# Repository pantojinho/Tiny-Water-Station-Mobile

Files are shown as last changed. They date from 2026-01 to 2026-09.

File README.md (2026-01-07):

# Tiny Water Station Mobile - ESP32

**Project:** Atmospheric Telemetry and Aviation Mobile Unit

**Version:** 1.1 (Updated with BMM350)

**Processor:** ESP32-S3 (AI Enabled)

---

## 1. Overview

The **Tiny Water Station Mobile** is a high-performance development board (DEV Board) designed for weather balloon missions, critical environmental monitoring, and aviation assistance. The system combines industrial-grade precision sensors with long-range telemetry and edge artificial intelligence processing.

---

## 2. Core Specifications

The system is centered on the **ESP32-S3-WROOM-1-N16R8** module, chosen for:

* **Processing:** Dual-core with AI acceleration instructions (TensorFlow Lite Micro).
* **Memory:** 16MB Flash and 8MB PSRAM (essential for sensor buffers and LCD graphics).
* **Datalogger:** Integrated MicroSD slot for "Black Box" recording (flight logs in .csv).

---

## 3. Sensor Architecture (I2C Bus)

The board uses a shared I2C bus (GPIO 47 SDA / GPIO 48 SCL) with the following components:

| Sensor | Model | Function | Critical Advantage |
| --- | --- | --- | --- |
| **Environment** | Bosch BME688 | Gas (VOC/VSC), Temp and Humidity | AI for gas and odor detection |
| **Altimetry** | Bosch BMP581 | Pressure and Altitude Pro | 5cm precision (high-sensitivity vario) |
| **Inertial** | Bosch BMA400 | Low-Power Accelerometer | Impact detection and power saving |
| **Compass** | **Bosch BMM350** | **High-Precision Magnetometer** | **Heading correction and stable orientation** |
| **Light/UV** | Lite-On LTR-390 | UV Index and Luxmetry | Solar radiation monitoring |
| **Battery** | MAX17048 | Fuel Gauge (Monitoring) | Real battery percentage without charge loss |

---

## 4. External Module Integration (Off-Board)

To ensure flexibility and facilitate 3D assembly, the items below are connected via headers, not soldered directly to the main SMD board.

### 4.1. GPS Module (AliExpress)

The PCB will have a dedicated **6-pin female header** (2.54mm pitch) for the external GPS module. The GPS module from AliExpress comes with a 6-pin female connector.

* **PCB Pinout (6-pin female header):**
* **Pin 1:** VCC - 3.3V (AP2112K regulator output)
* **Pin 2:** GND - Common ground
* **Pin 3:** RXD (GPIO 17) - Connects to GPS module TX
* **Pin 4:** TXD (GPIO 18) - Connects to GPS module RX
* **Pin 5:** Reserved / NC
* **Pin 6:** Reserved / NC

*Note: Standard GPS modules typically use 4 pins (VCC, GND, TX, RX), but the AliExpress module uses a 6-pin connector. Pins 5 and 6 are reserved for future use or can be left unconnected.*

### 4.2. Power System and Battery

* **Type:** Li-Po 3.7V Battery (Recommended above 1000mAh for long missions).
* **Connector:** JST-PH 2.0mm 2-pin (Soldered on PCB).
* **Charging:** Integrated MCP73831 circuit for USB-C charging.
* **Safety:** DW01A protection circuit to prevent overcharge and deep discharge.

---

## 5. Interface and Expansion

### 5.1. Communication and Display

* **LoRa CC68 915MHz:** Long-distance data transmission (dedicated SPI).
* **IPS LCD Display 1.14":** Real-time visual feedback (shared SPI).
* **Antennas:** U.FL (IPEX) connectors for radio and GPS.

### 5.2. Expansion Header (Future-Proof)

A side connector (1x08) for future additions:

* `3.3V`, `GND`, `SDA`, `SCL`, `GPIO 1 (Analog)`, `GPIO 2`, `5V (VBUS)`.

---

## 6. Firmware Reference Pinout

| Feature | ESP32-S3 Pin | Note |
| --- | --- | --- |
| **I2C SDA / SCL** | GPIO 47 / 48 | Bus for all sensors |
| **UART TX / RX** | GPIO 18 / 17 | Communication with external GPS |
| **SPI MOSI/MISO/SCK** | GPIO 11 / 13 / 12 | Common bus (LoRa, LCD, SD) |
| **LoRa CS / DIO1** | GPIO 10 / 14 | Semtech radio control |
| **SD Card CS** | GPIO 21 | Datalogger selection |
| **LCD CS / DC** | GPIO 9 / 15 | IPS Display control |

---

## 7. Notes for 3D Design and PCB (China)

1. **Magnetometer (BMM350):** Position the BMM350 as far as possible from magnetic sources (such as speakers or DC-DC converter inductors) to avoid compass interference.
2. **Air Flow:** The BME688 sensor needs an opening in the 3D case to "breathe" external air, otherwise it will only measure the internal case temperature.
3. **GPS Module:** The 6-pin female connector should be positioned so that the external module cable does not pass over the ESP32-S3 antenna (WiFi/BT).
4. **Battery:** In the 3D design, provide a mechanical support for the Li-Po battery. Avoid leaving it loose, as in weather balloons vibration and wind can disconnect the JST.

---

## 8. Additional Documentation

For more technical details and contribution guidelines, see:

* **📦 [PCB/Hardware](PCB/README.md)** - Schematics, layouts, BOM and 3D design
* **💻 [Software](software/README.md)** - Firmware, drivers, tools and tests
* **🤝 [Contributing](CONTRIBUTING.md)** - Complete guide for contributors (PCB and Software)

---

## 9. License

This project is licensed under the **MIT License**. See the [LICENSE](LICENSE) file for more details.

---

*Documentation generated to support hardware development and software integration.*

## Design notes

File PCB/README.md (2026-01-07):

# PCB / Hardware - Tiny Water Station Mobile

This folder contains all files related to hardware design, schematics, PCB layouts, and technical documentation for manufacturing.

---

## 📁 Directory Structure

```
PCB/
├── schematics/           # Electronic schematics
├── layouts/              # PCB Layouts (EDA files)
├── bom/                  # Bill of Materials (Component list)
├── 3d-models/            # 3D Models (case, brackets, etc.)
├── documentation/        # Technical documentation
└── revisions/            # Version control per hardware
```

---

## 📋 Current Content

### Version 1.1 (Current)

This version uses the following main components:

- **MCU:** ESP32-S3-WROOM-1-N16R8 (16MB Flash, 8MB PSRAM)
- **I2C Sensors:**
  - BME688 - Temperature, Humidity, Gas (VOC/VSC)
  - BMP581 - Pressure and Altitude Pro
  - BMA400 - Low-Power Accelerometer
  - BMM350 - High-Precision Magnetometer
  - LTR-390 - UV Index and Luxmetry
  - MAX17048 - Battery Fuel Gauge

- **Communication:**
  - LoRa CC68 915MHz
  - GPS (external 6-pin female connector, 2.54mm pitch)

- **Interfaces:**
  - IPS LCD Display 1.14" (SPI)
  - MicroSD Card (SPI)
  - Expansion Header 1x08

---

## 🛠️ Recommended Tools

### PCB Design

- **KiCad (7.x or higher):** Free and open-source software
- **Altium Designer:** Professional tool (requires license)
- **EasyEDA:** Web-based alternative

### 3D Modeling

- **Fusion 360:** Professional CAD (free for educational use)
- **FreeCAD:** Open-source alternative
- **OpenSCAD:** Script-based for parametric models

### BOM and Documentation

- **Excel/Google Sheets:** For component lists
- **Markdown:** For technical documentation

---

## 📌 Important Design Notes

### Sensor Placement

1. **BMM350 (Magnetometer):**
   - Position as far as possible from magnetic sources
   - Avoid DC-DC converter inductors
   - Keep distance from speakers (if any)

2. **BME688 (Gas Sensor):**
   - The 3D case needs an opening for ventilation
   - Air flow required for accurate measurements
   - Avoid hermetic encapsulation

3. **Antennas:**
   - U.FL connectors for GPS and LoRa
   - Keep free area for radiation
   - Avoid metal traces under antennas

### Manufacturing Requirements

- **Minimum trace width:** 6 mil (0.15mm) for signals
- **Minimum clearance:** 6 mil (0.15mm)
- **Mounting vias:** Use tented vias
- **Solder mask:** Cover critical areas
- **Silkscreen:** Clear markers for SMD components

### Required Gerber Files

When sending for manufacturing, include:
- `.GTL` - Top copper layer
- `.GBL` - Bottom copper layer
- `.GTO` - Top silkscreen
- `.GBO` - Bottom silkscreen
- `.GBS` - Bottom solder mask
- `.GTS` - Top solder mask
- `.GBO` - Board outline
- `.GTP` - Top paste
- `.GBP` - Bottom paste

---

## 🔄 Version Control

Each hardware version should have its own folder in `revisions/` section:

```
revisions/
├── v1.0/
│   ├── schematics/
│   ├── layouts/
│   └── bom_v1.0.csv
└── v1.1/
    ├── schematics/
    ├── layouts/
    └── bom_v1.1.csv
```

### Versioning Convention

- **Major:** Changes that make versions incompatible
- **Minor:** Backward-compatible additions
- **Patch:** Bug fixes

---

## 📦 Bill of Materials (BOM)

### Recommended Format

```csv
Ref,Value,Footprint,Quantity,Manufacturer,Part Number,Supplier,Supplier Part Number,Notes
U1,ESP32-S3-WROOM-1,N16R8,1,Espressif,ESP32-S3-WROOM-1-N16R8,Digikey,2877-ESP32-S3-WROOM-1-N16R8-CT,
U2,BME688,LGA-8,1,Bosch,BME688,Digikey,828-1083-1-ND,
...
```

### Required Fields

- **Ref:** Reference on PCB (U1, R1, C1, etc.)
- **Value:** Component value (10k, 0.1uF, etc.)
- **Footprint:** Footprint used in layout
- **Quantity:** Required quantity
- **Part Number:** Manufacturer part number
- **Supplier Part Number:** Supplier part number

---

## 🎯 3D Case Design

### Minimum Requirements

1. **Required Openings:**
   - BME688 sensor (ventilation)
   - LCD Display (visible)
   - USB-C connector (charging)
   - LED indicators
   - Antennas (GPS/LoRa) - transparent or external area

2. **Battery Support:**
   - Fixed compartment for Li-Po battery
   - Avoid vibration that can disconnect JST
   - Easy access for replacement

3. **Assembly:**
   - Mounting holes for PCB
   - Appropriate spacers/standoffs
   - Consider ESP32 thermal dissipation

### 3D Printing Files

Recommended to provide:
- **STL/OBJ:** For direct printing
- **STEP:** For CAD modification
- **Printing Instructions:**
  - Recommended material (PLA/PETG/ABS)
  - Infill %
  - Temperature
  - Layers

---

## 🔧 Assembly and Soldering

### Suggested Assembly Order

1. Passive components (resistors, capacitors)
2. Connectors and headers
3. Integrated circuits
4. Mechanical components (buttons, LEDs)
5. Modules via headers (GPS, LoRa)

### Soldering Notes

- Use flux solder for SMD components
- Recommended temperature: 350-370°C
- Maximum contact time: 3 seconds per pin
- Check continuity after assembly

---

## 📞 Contributing with Hardware

To contribute with new designs or improvements:

1. Create a branch following the pattern: `hardware/name-of-change`
2. Make your modifications
3. Test the schematic (DRC/ERC)
4. Update BOM if necessary
5. Document the changes
6. Open a Pull Request with detailed description

Consult the file `../CONTRIBUTING.md` for more details about the contribution process.

---

## 📚 Additional Resources

- [Component Datasheets](../README.md#3-sensor-architecture-i2c-bus)
- [Complete Pinout](../README.md#6-firmware-reference-pinout)
- [Contribution Documentation](../CONTRIBUTING.md)
- [China Manufacturing Guidelines](../README.md#7-notes-for-3d-design-and-pcb-china)

---

**Last Update:** 2026
**Version:** 1.1

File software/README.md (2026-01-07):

# Software - Tiny Water Station Mobile

This folder contains all source code, libraries, tools, and documentation related to software development for the ESP32-S3 of Tiny Water Station Mobile.

---

## 📁 Directory Structure

```
software/
├── firmware/             # Main firmware (ESP32-S3)
│   ├── src/              # Source files (.cpp, .c, .ino)
│   │   ├── main.cpp      # Main file
│   │   ├── sensors/      # Sensor drivers
│   │   ├── comms/        # Communication (LoRa, GPS, SD)
│   │   ├── display/      # LCD control
│   │   └── utils/        # Utility functions
│   ├── include/          # Headers (.h)
│   ├── platformio.ini    # PlatformIO configuration
│   └── CMakeLists.txt    # Build system (ESP-IDF)
├── libraries/            # Custom libraries
├── tools/                # Scripts and utilities
├── tests/                # Unit and integration tests
└── documentation/        # Technical documentation and APIs
```

---

## 🚀 Getting Started

### Requirements

- **PlatformIO** (CLI or VS Code extension) - Recommended
- **ESP-IDF** (optional, for native builds)
- **Python 3.8+** (for script tools)
- **Git** (for version control)

### Installation

#### Using PlatformIO (Recommended)

1. Install VS Code: https://code.visualstudio.com/
2. Install PlatformIO extension
3. Clone the repository:
   ```bash
   git clone https://github.com/your-username/Tiny-Water-Station-Mobile.git
   cd Tiny-Water-Station-Mobile/software/firmware
   ```
4. Open in VS Code
5. PlatformIO will automatically detect `platformio.ini`

#### Using ESP-IDF (Alternative)

```bash
# Clone the repository
git clone https://github.com/espressif/esp-idf.git
cd esp-idf
./install.sh esp32s3
. ./export.sh

# Clone and compile the project
git clone https://github.com/your-username/Tiny-Water-Station-Mobile.git
cd Tiny-Water-Station-Mobile/software/firmware
idf.py build
```

### Compilation and Upload

```bash
# Compile
pio run

# Upload to ESP32-S3
pio run --target upload

# Serial monitor
pio device monitor

# All together
pio run --target upload --target monitor
```

---

## 📦 Hardware Components (BOM)

### Required Hardware Components

The following hardware components are required for software development and testing:

| Component | Description | Quantity | Notes |
|---|---|---|---|
| **ESP32-S3-WROOM-1-N16R8** | Main microcontroller module | 1 | 16MB Flash, 8MB PSRAM |
| **BME688** | Environmental sensor (Temp, Humidity, Gas) | 1 | I2C address: 0x77 |
| **BMP581** | High-precision pressure sensor | 1 | I2C address: 0x76 |
| **BMA400** | Low-power accelerometer | 1 | I2C address: 0x40 |
| **BMM350** | High-precision magnetometer | 1 | I2C address: 0x12 |
| **LTR-390** | UV and ambient light sensor | 1 | I2C address: 0x53 |
| **MAX17048** | Battery fuel gauge | 1 | I2C address: 0x36 |
| **SX1262/CC68** | LoRa transceiver module | 1 | 915 MHz, SPI interface |
| **GPS Module** | GPS receiver module | 1 | NMEA protocol, UART interface |
| **IPS LCD Display 1.14"** | Color display | 1 | 135x240 pixels, SPI interface |
| **MicroSD Card** | Data storage | 1 | Minimum 4GB, FAT32 formatted |
| **Li-Po Battery** | Power source | 1 | 3.7V, 1000mAh+ recommended |
| **USB-C Cable** | Programming and charging | 1 | For ESP32 upload and battery charging |
| **JST-PH Connector** | Battery connector | 1 | 2-pin 2.0mm pitch |

### Development Tools

| Tool | Description | Purpose |
|---|---|---|
| **ESP32-S3 DevKit** | Development board | Initial testing before PCB |
| **Logic Analyzer** | Digital signal debugging | I2C, SPI, UART protocol analysis |
| **Multimeter** | Electrical measurements | Voltage, current, continuity testing |
| **Oscilloscope** | Signal visualization | Optional, for advanced debugging |
| **USB-UART Adapter** | Serial communication | GPS module testing (optional) |
| **LoRa Gateway** | LoRa receiver | Testing long-range transmission |

### Optional Accessories

| Component | Description | Purpose |
|---|---|---|
| **Antenna U.FL (LoRa)** | LoRa antenna | 915MHz, dipole or helical |
| **Antenna U.FL (GPS)** | GPS antenna | Active or passive, 1575.42MHz |
| **Push Buttons** | Manual controls | Testing emergency mode, configuration |
| **LEDs** | Status indicators | Visual feedback (optional) |
| **3D Printed Case** | Enclosure | Protects electronics during testing |

### Total Component Count

- **Sensors (I2C):** 6 components
- **Communication Modules:** 2 components (LoRa + GPS)
- **Interfaces:** 2 components (Display + SD Card)
- **Power System:** 2 components (Battery + Charger)
- **Total Unique Components:** ~12 items

### Notes

1. All I2C sensors share the same bus (SDA: GPIO 47, SCL: GPIO 48)
2. SD Card and Display share the same SPI bus (different CS pins)
3. LoRa module uses dedicated SPI interface
4. GPS uses UART (GPIO 17/18)
5. Ensure all sensors are properly powered (3.3V) before testing software

---

## 📡 Sensors and Drivers

### I2C Architecture

All sensors are on the I2C bus:
- **SDA:** GPIO 47
- **SCL:** GPIO 48

### Implemented Drivers

| Sensor | Driver | Base Library | Status |
|---|---|---|---|
| BME688 | `bme688.cpp` | Bosch BSEC 2.x | ✅ Implemented |
| BMP581 | `bmp581.cpp` | Bosch BMP5-Sensor-API | ✅ Implemented |
| BMA400 | `bma400.cpp` | Bosch BMA400-API | ✅ Implemented |
| BMM350 | `bmm350.cpp` | Bosch BMM350-API | ✅ Implemented |
| LTR-390 | `ltr390.cpp` | Adafruit LTR3XX | ✅ Implemented |
| MAX17048 | `max17048.cpp` | Adafruit MAX1704X | ✅ Implemented |

### Initialization Example

```cpp
#include "sensors/bme688.h"

void setup() {
    Serial.begin(115200);
    
    // Initialize BME688
    if (bme688_init()) {
        Serial.println("BME688 initialized successfully!");
    } else {
        Serial.println("Error initializing BME688");
    }
}
```

---

## 📡 Communication

### LoRa (SX126x/CC68)

- **Interface:** SPI
- **Pins:**
  - MOSI: GPIO 11
  - MISO: GPIO 13
  - SCK: GPIO 12
  - CS: GPIO 10
  - DIO1: GPIO 14
- **Frequency:** 915 MHz (South America)
- **Library:** RadioLib

### GPS

- **Interface:** UART
- **Pins:**
  - RX (GPIO 17): Receives from GPS
  - TX (GPIO 18): Sends to GPS
- **Baud rate:** 9600 (configurable)
- **Protocol:** NMEA

### SD Card

- **Interface:** SPI (shared)
- **CS Pin:** GPIO 21
- **Format:** FAT32
- **Function:** Flight datalogger (CSV)

---

## 🖥️ LCD Display

### Specifications

- **Model:** IPS LCD 1.14"
- **Resolution:** 135x240 pixels
- **Interface:** SPI (shared)
- **Pins:**
  - CS: GPIO 9
  - DC: GPIO 15
- **Library:** TFT_eSPI or Adafruit ST7735

### Interface Layout

```
┌─────────────────────────┐
│ Alt: 1245m  Vel: 12.3m/s│  Top bar
├─────────────────────────┤
│ Temp: 25.4°C           │
│ Umid: 68%              │
│ Pres: 1013.2 hPa       │  Sensor data
│ UV: 3.2 Lux: 45000     │
├─────────────────────────┤
│ Bat: 85%  GPS: Fix     │  System status
│ LoRa: TX 2.4k/s        │
└─────────────────────────┘
```

---

## 📊 Datalogger

### Log Format (CSV)

The system records data in CSV format with timestamp:

```csv
timestamp,latitude,longitude,altitude,velocity,temperature,humidity,pressure,gas_resistance,accel_x,accel_y,accel_z,mag_x,mag_y,mag_z,heading,uv_index,lux,battery_percent,lo_rssi
2024-01-06T14:30:00.000Z,-23.5505,-46.6333,1245.2,12.3,25.4,68,1013.2,45000,0.02,0.01,9.81,-23.5,12.3,-45.2,145.3,3.2,45000,85,-65
```

### File Rotation

- **Maximum file size:** 10 MB
- **File name:** `flight_log_YYYYMMDD_HHMMSS.csv`
- **Total logs:** Up to 50 files (after that, the oldest is deleted)

---

## 🔧 Configuration

### platformio.ini

```ini
[env:esp32-s3]
platform = espressif32
board = esp32-s3-devkitc-1
framework = arduino

; Memory settings
board_build.arduino.memory_type = qio_opi
board_build.partitions = huge_app.csv

; Serial settings
monitor_speed = 115200
monitor_filters = esp32_exception_decoder

; Libraries
lib_deps = 
    adafruit/Adafruit Unified Sensor
    adafruit/Adafruit BME680 Library
    RadioLib
    TFT_eSPI
    SPIFFS

; Compilation flags
build_flags = 
    -DARDUINO_USB_MODE=1
    -DARDUINO_USB_CDC_ON_BOOT=1
    -DBOARD_HAS_PSRAM
    -mfix-esp32-psram-cache-issue
```

---

## 🧪 Tests

### Running Tests

```bash
# Test compilation
pio run --target test

# Run all tests
pio test

# Specific test
pio test --target test_bme688
```

### Available Tests

| Test | Description |
|---|---|
| `test_i2c` | Tests communication with all I2C sensors |
| `test_lora` | Tests LoRa transmission and reception |
| `test_gps` | Tests NMEA parsing |
| `test_sd` | Tests SD card writing and reading |
| `test_display` | Tests LCD rendering |

---

## 📚 Documentation

### API Documentation

See the `documentation/` folder for:

- **API Reference:** Complete documentation of public functions
- **Sensor Drivers:** Detailed guide for each sensor
- **Configuration:** Configurable parameters
- **Integration Guide:** Guide for integrating new modules

### Inline Documentation

All public functions have Doxygen documentation:

```cpp
/**
 * @brief Reads current altitude from BMP581 sensor
 * 
 * @return float Altitude in meters above sea level
 * 
 * @note Requires BMP581 to be initialized
 * @see init_bmp581()
 */
float read_altitude();
```

---

## 🎯 Operation Modes

### Normal Mode

Standard operation for monitoring:
- Sensors read at 10 Hz
- LoRa transmitting at 1 Hz
- Display updated at 5 Hz
- Continuous SD logging

### Power Saving Mode

For long missions:
- Sensors read at 1 Hz
- LoRa transmitting at 0.1 Hz (1 msg/10s)
- Display off or updated at 1 Hz
- ESP32 in deep sleep between readings

### Emergency Mode

Triggered by:
- Battery < 10%
- Temperature > 60°C
- Impact detection (BMA400)

Actions:
- Stop LoRa transmissions
- Log only critical data
- LEDs flashing red

---

## 🐛 Debugging

### Debug Logs

```cpp
// Available log levels
ESP_LOGE("TAG", "Error: %s", message);   // Error
ESP_LOGW("TAG", "Warning: %s", message);  // Warning
ESP_LOGI("TAG", "Info: %s", message);   // Info
ESP_LOGD("TAG", "Debug: %s", message);  // Debug
ESP_LOGV("TAG", "Verbose: %s", message);// Verbose
```

### Serial Monitoring

```bash
# Open serial monitor with filter
pio device monitor --filter time,esp32_exception_decoder

# Export logs to file
pio device monitor > debug.log
```

---

## 🤝 Contributing with Software

To contribute:

1. **Create a branch:**
   ```bash
   git checkout -b software/new-feature
   ```

2. **Make your modifications:**
   - Follow code standards (C/C++)
   - Add tests for new features
   - Update documentation

3. **Test:**
   ```bash
   pio test
   pio run
   ```

4. **Commit and Push:**
   ```bash
   git add .
   git commit -m "Add feature X"
   git push origin software/new-feature
   ```

5. **Open a Pull Request** following the template in `../CONTRIBUTING.md`

---

## 📚 Resources

- [PlatformIO Documentation](https://docs.platformio.org/)
- [ESP32-S3 Technical Reference Manual](https://www.espressif.com/sites/default/files/documentation/esp32-s3_technical_reference_en.pdf)
- [Bosch Sensor API Documentation](https://github.com/BoschSensortec/BMI160_SensorAPI)
- [Contribution Documentation](../CONTRIBUTING.md)
- [Reference Pinout](../README.md#6-firmware-reference-pinout)

---

**Last Update:** 2026
**Firmware Version:** 2.1.0
**Framework:** Arduino / ESP-IDF 5.x

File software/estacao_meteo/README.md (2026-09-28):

# Estação Meteorológica Mini — Waveshare ESP32-S3-Touch-AMOLED-1.64

Firmware Arduino completo de estação meteorológica para a placa
**Waveshare ESP32-S3-Touch-AMOLED-1.64** (AMOLED 280×456 QSPI + touch FT3168 +
IMU QMI8658) com sensor externo **Adafruit BMP581** (temperatura + pressão, I²C 0x47).

board

## Funcionalidades

- **Relógio NTP** com fuso da cidade escolhida; geo-IP apenas como configuração inicial
- **Previsão do tempo** Open-Meteo (temperatura externa, mín/máx, código WMO e ícones de sol, lua, nuvens, chuva e tempestade no painel web)
- **Alerta de chuva**: varra as próximas 12 h; probabilidade ≥ 40 % → banner "leva guarda-chuva"
- **Sensores locais**: BMP581 (temp/pressão), altitude barométrica (vs MSL em tempo real), QMI8658 (giro/accel)
- **Umidade relativa** via Open-Meteo
- **Tela horizontal LVGL 9**, 456×280, USB à direita, sem menus ou leitura do touch; temperatura do BMP581 em destaque, clima em tamanho menor e IP em faixa inferior
- **Web server** em `http://<ip>/` (ou `estacao.local`): monitor ao vivo + busca de cidade e configuração (WiFi, lat/lon, fuso) — APIs `/api/status` e `/api/config`
- **Log em cartão microSD** (`/estacao.csv`, 1 linha/min) — CSV pronto pra planilha
- AP de configuração (`EstacaoMeteo` / `12345678`), endereço `http://192.168.4.1/`: imediato sem rede salva; após aproximadamente 20 s sem conectar no início; após 60 s desconectado durante o uso

## Hardware

| Função | Pino |
|---|---|
| I²C (BMP581 + touch + IMU) | SDA=GPIO47, SCL=GPIO48 |
| Display AMOLED (QSPI) | CS=9, CLK=10, D0..D3=11..14, RST=21 |
| microSD | CS=38, MOSI=39, MISO=40, CLK=41 |
| BMP581 alimentação | 3V3 e GND do header |

O painel CO5300 permanece na resolução nativa 280×456 e rotação de hardware 0.
O firmware gira os pixels em software e usa uma interface lógica 456×280 fixa.
Coloque a placa com o conector USB à direita. Não há rotação automática.
As áreas de atualização são alinhadas em pares de pixels antes da rotação,
como exige o CO5300, para evitar rastros nas atualizações parciais.
O painel web também destaca a temperatura local do BMP581; o tempo da
cidade aparece como informação secundária, identificado como Internet.

## Build & Flash (arduino-cli)

```bash
arduino-cli lib install "lvgl@9.2.2" "Adafruit BMP5xx Library@1.0.2" "ArduinoJson@7.4.2" "GFX Library for Arduino@1.6.8"
arduino-cli compile --fqbn "esp32:esp32:esp32s3:CDCOnBoot=cdc,FlashSize=16M,PSRAM=opi,PartitionScheme=app3M_fat9M_16MB,UploadSpeed=921600" .
arduino-cli upload -p /dev/ttyACM0 --fqbn "esp32:esp32:esp32s3:CDCOnBoot=cdc,FlashSize=16M,PSRAM=opi,PartitionScheme=app3M_fat9M_16MB,UploadSpeed=921600" .
```

> Copie `lv_conf.h` para `~/Arduino/libraries/lv_conf.h` antes de compilar;
> o Arduino CLI não faz essa cópia automaticamente.

## Acesso e configuração

O touchscreen está desativado: nenhum dispositivo de entrada LVGL é criado,
e o FT3168 não é consultado. Configure tudo pelo endereço exibido na tela.
As consultas HTTP da previsão rodam em tarefa separada para não bloquear a UI.

Se a rede salva estiver indisponível, conecte o celular/computador ao Wi-Fi
**EstacaoMeteo**, senha **12345678**, e abra **http://192.168.4.1/**.
Preencha a rede e a senha em Configurações. Ao salvar uma mudança de Wi-Fi,
a página reinicia a estação; conecte à rede escolhida e use o novo IP da tela.
A localização e a rede ficam salvas na memória após desligar.

Os fusos brasileiros `America/...` mais comuns são convertidos para regras POSIX
antes de configurar o relógio do ESP32. Para outro local, informe diretamente
uma regra POSIX no campo de fuso horário.

## Escolher a cidade

Abra `http://<ip>/` no navegador, entre em **Configurações**, digite a cidade e
clique em **Buscar**. Escolha o resultado correto conferindo estado e país, depois
clique em **Salvar alterações**. A página preenche latitude, longitude e fuso
horário com os dados do Open-Meteo. A previsão e o relógio atualizam sem reiniciar;
a escolha fica salva após desligar o aparelho. Se a busca estiver indisponível,
latitude, longitude e fuso também podem ser informados manualmente. Uma troca de rede Wi-Fi salva pela página reinicia a estação automaticamente.

## Arquivos

| Arquivo | O que é |
|---|---|
| `main.cpp` | firmware principal (UI + sensores + web + SD) |
| `estacao_meteo.ino` | entrada vazia para Arduino IDE/CLI; main.cpp é compilado automaticamente |
| `platformio.ini` | configuração de compilação pelo PlatformIO |
| `web_page.h` | painel web e formulário de configuração |
| `lv_conf.h` | configuração LVGL (RGB565, fontes Montserrat) |
| `icon_*.h` | emojis OpenMoji 72×72 em RGB565 (CC-BY-SA 4.0) |
| `icons.py` | gerador dos `icon_*.h` a partir de `assets/*.png` |
| `assets/` | PNGs origem (OpenMoji) |
| `test_display/` | sketch mínimo de teste de display+touch |

## Armadilhas dessa placa (learnings)

1. **Nunca chame `gfx->setRotation()` em runtime** — o CO5300 não suporta
   reprogramação do MADCTL após init → listras/corrupção. Painel fixo no construtor.
2. **QMI8658**: habilitar auto-incremento I²C (CTRL1=0x60); dados em 0x35..0x3F.
3. **Adafruit BMP5xx**: `pressure` já retorna hPa.
4. **Rotação horizontal**: o flush gira tanto a área quanto os pixels RGB565;
   alterar apenas a resolução ou a rotação lógica não gira os pixels do CO5300.
5. Serial CDC do S3 exige DTR ativo (pyserial: `p.dtr = True`).

## Origem

Derivado do projeto de telemetria [Tiny-Water-Station-Mobile](https://github.com/pantojinho/Tiny-Water-Station-Mobile)
(reaproveitado: BMP581 da BOM, estrutura de log em SD e leitura periódica de sensores).

## Licença

MIT

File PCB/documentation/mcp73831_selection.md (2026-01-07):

# MCP73831 Battery Charger Selection Guide

## Overview

The **MCP73831** is a linear charge management controller for single-cell lithium-ion or lithium-polymer batteries. This document explains which variant to use for the Tiny Water Station Mobile project.

---

## Available Variants on LCSC

Based on [LCSC Electronics](https://www.lcsc.com/), the following MCP73831 variants are available:

### 1. MCP73831-2DCI/MC (Recommended)
- **Voltage Regulation:** 4.2V (standard for 3.7V Li-Po batteries)
- **Package:** DFN-8-EP (2x3mm)
- **LCSC Part Number:** C635037
- **Link:** [MCP73831-2DCI/MC on LCSC](https://lcsc.com/product-detail/Battery-Management-ICs_Microchip-Tech-MCP73831-2DCI-MC_C635037.html)
- **Advantages:**
  - Standard 4.2V charge voltage (perfect for 3.7V Li-Po)
  - DFN package is easier to solder than TDFN
  - Good thermal performance
  - Suitable for space-constrained designs

### 2. MCP73831-2ACI/MC (Alternative)
- **Voltage Regulation:** 4.2V
- **Package:** TDFN-8-EP (2x3mm)
- **LCSC Part Number:** C150772
- **Link:** [MCP73831-2ACI/MC on LCSC](https://lcsc.com/product-detail/_MICROCHIP_MCP73831-2ACI-MC_MCP73831-2ACI-MC_C150772.html)
- **Note:** Similar to 2DCI but with slightly different thermal characteristics

### 3. MCP73831-5ACI/MC (Not Recommended)
- **Voltage Regulation:** 4.5V
- **Package:** DFN-8-EP (2x3mm)
- **LCSC Part Number:** C635040
- **Note:** 4.5V is too high for standard 3.7V Li-Po batteries (would damage them)

---

## Selection for Tiny Water Station Mobile

### Recommended Part: **MCP73831-2DCI/MC**

**Why this variant?**

1. **Correct Voltage:** 4.2V is the standard charge termination voltage for 3.7V Li-Po batteries
2. **Package:** DFN-8-EP is suitable for SMD assembly and has good thermal properties
3. **Availability:** Available on LCSC with part number C635037
4. **Compatibility:** Works perfectly with the DW01A battery protection IC

### Specifications

- **Input Voltage:** 4.5V to 6.0V (USB-C provides 5V)
- **Charge Current:** Programmable via external resistor (typically 500mA to 1000mA)
- **Charge Termination:** 4.2V ± 0.05V
- **Package:** DFN-8-EP (2mm x 3mm)
- **Pin Count:** 8 pins with exposed thermal pad

---

## PCB Design Considerations

### Footprint Requirements

- **Package:** DFN-8-EP (2mm x 3mm)
- **Pitch:** 0.5mm (fine pitch - requires careful routing)
- **Thermal Pad:** Exposed pad on bottom (must be connected to GND for heat dissipation)
- **Solder Paste:** Use stencil with appropriate aperture for fine-pitch components

### Layout Guidelines

1. **Thermal Pad:** Connect the exposed pad to a large ground plane for heat dissipation
2. **Input Capacitor:** Place 10µF ceramic capacitor close to VIN pin
3. **Output Capacitor:** Place 10µF ceramic capacitor close to VOUT pin
4. **Charge Current Resistor:** Place programming resistor (R_PROG) close to PROG pin
5. **Thermal Vias:** Add thermal vias under the thermal pad if possible

### Typical Application Circuit

```
USB-C (5V) ──┬── VIN (Pin 1)
             │
             ├── 10µF ── GND
             │
             └── MCP73831-2DCI/MC
                    │
                    ├── VOUT (Pin 8) ── Li-Po Battery (+)
                    │
                    ├── PROG (Pin 2) ── R_PROG ── GND
                    │
                    └── STAT (Pin 3) ── LED (optional status indicator)
```

### Charge Current Programming

The charge current is set by the resistor connected to the PROG pin:

| R_PROG (kΩ) | Charge Current (mA) |
|---|---|
| 2.0 | 1000 |
| 2.5 | 800 |
| 3.0 | 650 |
| 4.0 | 500 |
| 5.0 | 400 |

**Recommended:** 2.5kΩ for 800mA charge current (safe for 1000mAh battery)

---

## Ordering Information

### LCSC Ordering Details

- **Manufacturer:** Microchip Technology
- **Part Number:** MCP73831-2DCI/MC
- **LCSC Part Number:** C635037
- **Package:** DFN-8-EP (2x3mm)
- **Minimum Order Quantity:** Check LCSC website
- **Stock Status:** Verify availability before ordering

### Alternative Suppliers

If LCSC is out of stock, consider:
- **Digikey:** MCP73831T-2DCI/OT (similar part, different package)
- **Mouser:** Check for MCP73831 variants
- **Arrow:** Alternative distributor

---

## Testing and Validation

### Before Assembly

1. Verify package dimensions match PCB footprint
2. Check thermal pad connection to ground plane
3. Verify input/output capacitor placement
4. Confirm charge current resistor value

### After Assembly

1. **Voltage Test:** Measure VOUT should be 4.2V when battery is fully charged
2. **Current Test:** Measure charge current should match programmed value
3. **Thermal Test:** Monitor temperature during charging (should stay below 85°C)
4. **Status LED:** Verify STAT pin indicates charge status correctly

---

## Troubleshooting

### Common Issues

1. **No Charging:**
   - Check VIN voltage (should be 4.5V-6.0V)
   - Verify PROG resistor value
   - Check battery connection

2. **Overheating:**
   - Ensure thermal pad is properly soldered to ground
   - Check charge current (may be too high)
   - Verify adequate PCB copper area for heat dissipation

3. **Incorrect Charge Voltage:**
   - Verify correct variant (should be 2DCI for 4.2V)
   - Check for counterfeit parts

---

## References

- [LCSC Product Page - MCP73831-2DCI/MC](https://lcsc.com/product-detail/Battery-Management-ICs_Microchip-Tech-MCP73831-2DCI-MC_C635037.html)
- [Microchip MCP73831 Datasheet](https://ww1.microchip.com/downloads/en/DeviceDoc/20001984g.pdf)
- [LCSC Electronics Homepage](https://www.lcsc.com/)

---

**Last Updated:** 2026
**Selected Part:** MCP73831-2DCI/MC (LCSC: C635037)

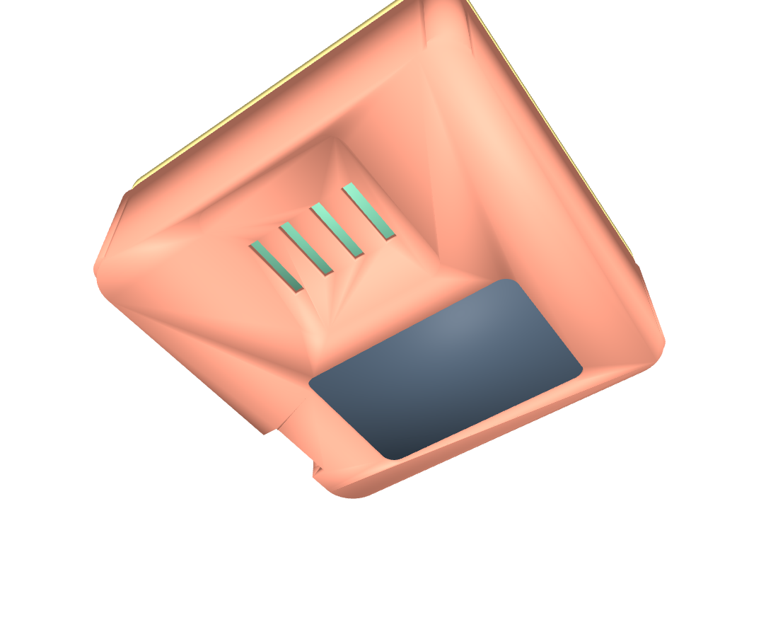
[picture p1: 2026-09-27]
case/v3-horizontal/visual_conjunto.png

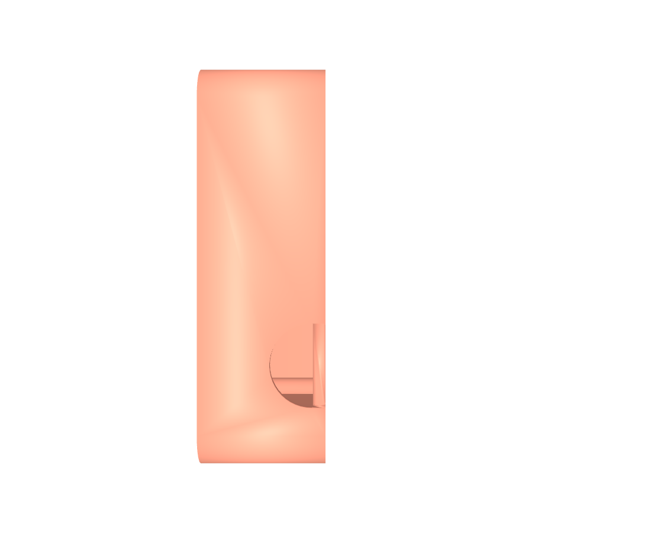
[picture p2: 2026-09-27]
case/v3-horizontal/visual_usb_lateral.png

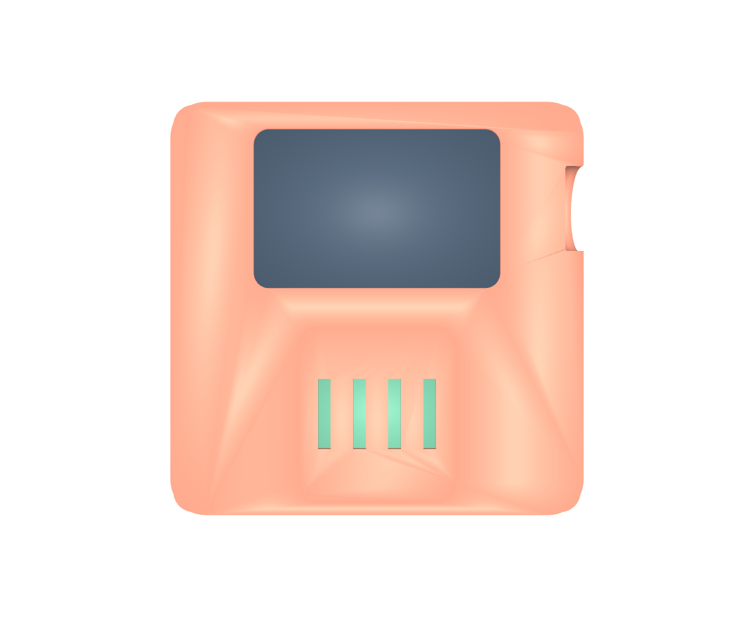
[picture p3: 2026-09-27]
case/v3-horizontal/visual_frente.png

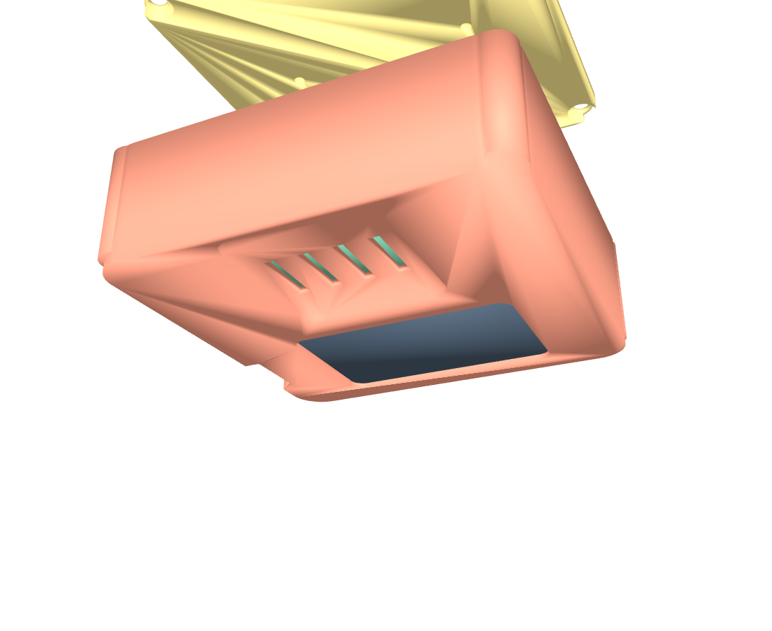
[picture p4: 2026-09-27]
case/v3-horizontal/visual_aberta.png

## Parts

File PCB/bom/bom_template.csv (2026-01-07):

ID | Name | Designator | Footprint | Quantity | Manufacturer Part | Manufacturer | Supplier | Supplier Part | Price (USD) | Total Price | Notes
1 | ESP32-S3-WROOM-1-N16R8 | ESP32 | WIRELM-SMD_ESP32-S3-WROOM-1 | 1 | ESP32-S3-WROOM-1-N16R8 | Espressif | LCSC | C2913202 | 5.613 | 5.613 | WROOM module with 16MB Flash | 8MB PSRAM
2 | BME688 | SENSOR(T | H | G | B) | LGA-8_L3.0-W3.0-P0.80_BME688 | 2 | BME688 | Bosch Sensortec | LCSC | C3664478 | 9.33 | 18.66 | Gas | temperature | humidity sensor with AI
3 | BMP581 | ALTIMETER | LGA-10_L2.0-W2.0-P0.50-TL_BMP581 | 1 | BMP581 | Bosch Sensortec | LCSC | C5362283 | 2.174 | 2.174 | High-precision pressure and altimeter
4 | BMA400 | ACCELEROMETER | LGA-12_L2.0-W2.0-P0.50-BL | 1 | BMA400 | Bosch Sensortec | LCSC | C437655 | 2.833 | 2.833 | Low-power accelerometer
5 | BMM350 | COMPASS | WLCSP-9_L1.3-W1.3-R3-C3-P0.40-TL | 1 | BMM350 | Bosch Sensortec | LCSC | C17225907 | 2.278 | 2.278 | High-precision magnetometer
6 | LTR-390UV-01 | UV_SENSOR | SENSOR-SMD_LTR-390UV-01 | 1 | LTR-390UV-01 | Lite-On | LCSC | C492374 | 1.825 | 1.825 | UV index and ambient light sensor
7 | MAX17048G+T10 | BATTERY_GAUGE | TDFN-8_L2.0-W2.0-P0.50-BL-EP1.2 | 1 | MAX17048G+T10 | Maxim Integrated | LCSC | C2682616 | 2.403 | 2.403 | Fuel gauge for Li-Po battery
8 | AP2112K-3.3 | LDO_REGULATOR | SOT-223-3 | 1 | AP2112K-3.3TRG1 | Diodes Incorporated | LCSC | TBD | 0.00 | 0.00 | 3.3V LDO regulator | 800mA
9 | MCP73831-2DCI/MC | BATTERY_CHARGER | DFN-8_L3.0-W2.0-P0.50-BL-EP1.6 | 1 | MCP73831-2DCI/MC | Microchip Technology | LCSC | C635037 | 1.644 | 1.644 | Li-Po battery charger 4.2V | DFN-8-EP package
10 | DW01A | BATTERY_PROTECTION | SOT-23-6 | 1 | DW01A | Fortune DW01A | LCSC | TBD | 0.00 | 0.00 | Battery protection IC
11 | LoRa-CC68-C1-915MHz | LORA_MODULE | WIRELM-SMD_16P-L16.0-W16.0-P2.00_LORA-CC68-915MHz-TCXO | 1 | LoRa-CC68-C1-915MHz | G-NiceRF | LCSC | C5126740 | 4.534 | 4.534 | LoRa transceiver 915MHz with TCXO
12 | N114-2413THBIG01-H13 | DISPLAY_LCD | LCD-SMD_1.14IPS-LCD | 1 | N114-2413THBIG01-H13 | Wisevision | LCSC | C2890618 | 2.451 | 2.451 | 1.14" IPS LCD display
13 | TYPE-C16PIN | USB-C | USB-C-SMD_TYPE-C16PIN | 1 | TYPE-C16PIN | Shou Han | LCSC | C393939 | 0.06 | 0.06 | USB-C connector for charging
14 | TF PUSH | SD_CARD | TF-SMD_TF-PUSH | 1 | TF PUSH | Shou Han | LCSC | C393941 | 0.06 | 0.06 | MicroSD card slot with push mechanism
15 | Header 6-pin Female | GPS_HEADER | PH-2.54MM-6P-FEMALE | 1 | PHR-6-F | Generic | LCSC | TBD | 0.00 | 0.00 | Female header 2.54mm pitch 6-pin for GPS module (AliExpress compatible)
16 | Header 8-pin | EXPANSION_HEADER | PH-2.0MM-8P | 1 | PHR-8 | JST | LCSC | TBD | 0.00 | 0.00 | Expansion header
17 | Crystal 32MHz | CRYSTAL | HC49/US | 1 | ABLS-32.000MHZ-D2Y-T | Abracon | LCSC | TBD | 0.00 | 0.00 | Main crystal for ESP32-S3
18 | 10k Resistor | PULLUP_R1 | 0603 | 1 | RC0603FR-0710KL | Yageo | LCSC | TBD | 0.00 | 0.00 | Pull-up resistor
19 | 10k Resistor | PULLUP_R2 | 0603 | 1 | RC0603FR-0710KL | Yageo | LCSC | TBD | 0.00 | 0.00 | Pull-up resistor
20 | 4.7k Resistor | I2C_PULLUP_R3 | 0603 | 1 | RC0603FR-074K7L | Yageo | LCSC | TBD | 0.00 | 0.00 | I2C pull-up resistor
21 | 4.7k Resistor | I2C_PULLUP_R4 | 0603 | 1 | RC0603FR-074K7L | Yageo | LCSC | TBD | 0.00 | 0.00 | I2C pull-up resistor
22 | 10uF Capacitor | BULK_C1 | 0603 | 1 | CL10A106KP8NNNC | Samsung | LCSC | TBD | 0.00 | 0.00 | Bulk capacitor
23 | 100nF Capacitor | DECOUPLING_C2 | 0603 | 1 | C0603C104K4RACTU | KEMET | LCSC | TBD | 0.00 | 0.00 | Decoupling capacitor
24 | 10uF Capacitor | BULK_C3 | 0603 | 1 | CL10A106KP8NNNC | Samsung | LCSC | TBD | 0.00 | 0.00 | Bulk capacitor
25 | 100nF Capacitor | DECOUPLING_C4 | 0603 | 1 | C0603C104K4RACTU | KEMET | LCSC | TBD | 0.00 | 0.00 | Decoupling capacitor
26 | Reset Button | RESET_SW | TS-1188 | 1 | TS-1188A-04060-B | Korean Hroparts Elec | LCSC | TBD | 0.00 | 0.00 | Reset button
27 | Boot Button | BOOT_SW | TS-1188 | 1 | TS-1188A-04060-B | Korean Hroparts Elec | LCSC | TBD | 0.00 | 0.00 | Boot button
28 | Red LED | POWER_LED | 0603 | 1 | LTST-C191KRKT | Lite-On | LCSC | TBD | 0.00 | 0.00 | Power indicator LED
29 | Green LED | STATUS_LED | 0603 | 1 | LTST-C191KGKT | Lite-On | LCSC | TBD | 0.00 | 0.00 | Status indicator LED
30 | Blue LED | LORA_LED | 0603 | 1 | LTST-C191KBKT | Lite-On | LCSC | TBD | 0.00 | 0.00 | LoRa transmission indicator LED
31 | Li-Po Battery 1000mAh | BATTERY | JST-PH 2.0 | 1 | N/A | N/A | LCSC | TBD | 0.00 | 0.00 | 1000mAh Li-Po battery
32 | LoRa Antenna | ANTENNA_LORA | U.FL | 1 | 0734120110 | Molex | LCSC | TBD | 0.00 | 0.00 | 915MHz LoRa antenna
34 | Main PCB | PCB | Custom | 1 | N/A | N/A | N/A | N/A | 0.00 | 0.00 | 4-layer PCB | FR4 | thickness 1.6mm
35 | 3D Printed Case | CASE | Custom | 1 | N/A | N/A | N/A | N/A | 0.00 | 0.00 | PLA or PETG | 3D printed enclosure
 |  |  | TOTAL COMPONENTS: 35 items |  |  |  |  |  |  | 44.555 | 44.555 | Main components with pricing: 12 items

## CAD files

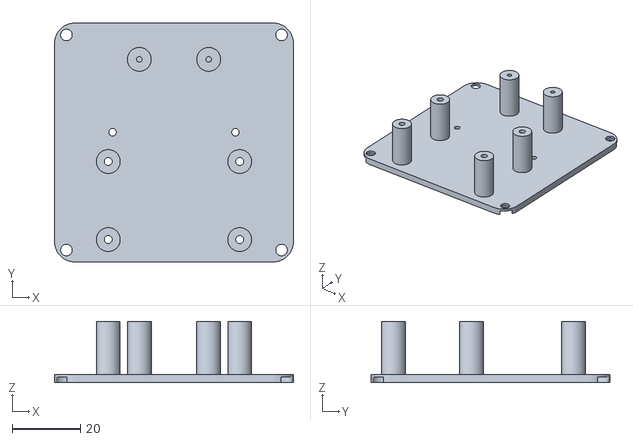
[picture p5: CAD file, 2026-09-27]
case/v3-horizontal/caixa_integrada_tampa-3.stl
70.0 x 70.0 x 17.9

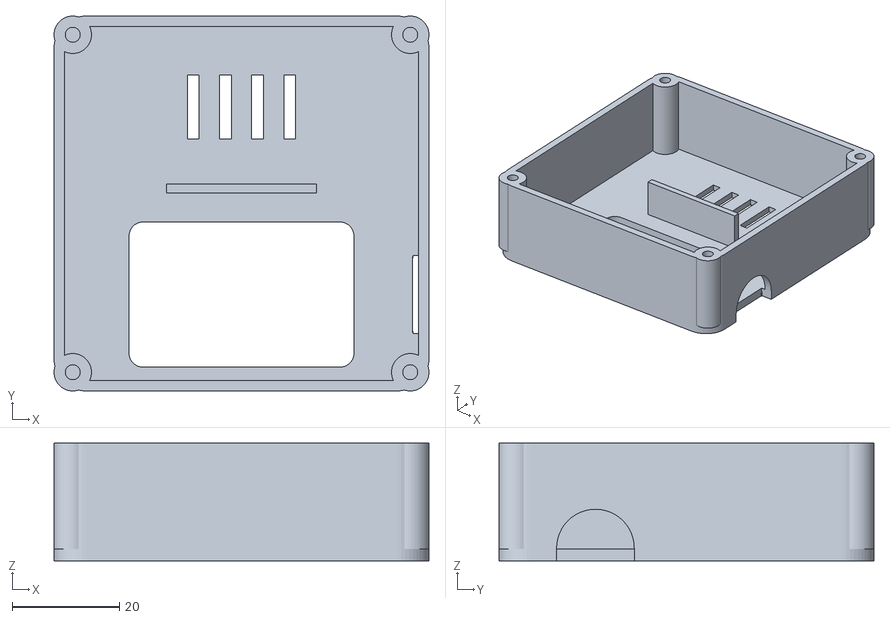
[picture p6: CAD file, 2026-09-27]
case/v3-horizontal/caixa_integrada_corpo-3.stl
70.0 x 70.0 x 22.0

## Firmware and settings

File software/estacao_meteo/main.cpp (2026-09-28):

/*
 * Estação Meteorológica Mini
 * Waveshare ESP32-S3-Touch-AMOLED-1.64 (CO5300 QSPI 280x456 + FT3168 touch + QMI8658 IMU)
 * Sensor externo: Adafruit BMP581 (I2C 0x47 no barramento GPIO47/48)
 *
 * - Relógio NTP + data (fuso via geo-IP, ajustável pela web)
 * - Previsão/tempo atual via Open-Meteo (localização via geo-IP ou manual na web)
 * - BMP581: temperatura/pressão locais; QMI8658: giro/acel
 * - Tela fixa, sem touch, com endereço para configuração pelo navegador
 * - Modo AP automático se o Wi-Fi salvo não conectar ou cair por 60 s
 * - Web server: http://estacao.local ou IP — monitor + configuração (WiFi, local, fuso)
 */

#include <Arduino.h>

static void uiTick();
#include <WiFi.h>
#include <WiFiMulti.h>
#include <WebServer.h>
#include <DNSServer.h>
#include <ESPmDNS.h>
#include <time.h>
#include <Wire.h>
#include <Preferences.h>
#include <ArduinoJson.h>
#include <HTTPClient.h>
#include <lvgl.h>
#include <Arduino_GFX_Library.h>
#include <SD.h>
#include <SPI.h>
#include "Adafruit_BMP5xx.h"
#include "icon_sun.h"
#include "icon_cloud.h"
#include "icon_suncloud.h"
#include "icon_rain.h"
#include "icon_storm.h"
#include "icon_sunrain.h"
#include "icon_snow.h"
#include "icon_fog.h"

// ============================ WiFi (credenciais iniciais) ====================
#define WIFI_SSID_DEFAULT ""
#define WIFI_PASS_DEFAULT ""

// ============================ Pinos / hardware ===============================
#define TOUCH_SDA 47
#define TOUCH_SCL 48
#define I2C_HZ 100000

#define QMI_ADDR 0x6B
#define BMP_ADDR BMP5XX_ALTERNATIVE_ADDRESS // 0x47

Arduino_DataBus *bus = new Arduino_ESP32QSPI(9, 10, 11, 12, 13, 14);
Arduino_GFX *gfx = new Arduino_CO5300(bus, 21 /*RST*/, 0 /*rot NATIVO — 180° fica por conta do LVGL*/, 280, 456,
                                      20, 0, 180, 24);

// ============================ Config persistente =============================
Preferences prefs;
struct Cfg {
  char ssid[33];
  char pass[65];
  float lat;
  float lon;
  char city[96];
  char tz[64];
} cfg;

void cfgLoad() {
  memset(&cfg, 0, sizeof(cfg));
  prefs.begin("estacao", true);
  String s;
  s = prefs.getString("ssid", WIFI_SSID_DEFAULT);
  strlcpy(cfg.ssid, s.c_str(), sizeof(cfg.ssid));
  s = prefs.getString("pass", WIFI_PASS_DEFAULT);
  strlcpy(cfg.pass, s.c_str(), sizeof(cfg.pass));
  cfg.lat = prefs.getFloat("lat", 0);
  cfg.lon = prefs.getFloat("lon", 0);
  s = prefs.getString("city", "");
  strlcpy(cfg.city, s.c_str(), sizeof(cfg.city));
  s = prefs.getString("tz", "America/Sao_Paulo");
  strlcpy(cfg.tz, s.c_str(), sizeof(cfg.tz));
  prefs.end();
}
void cfgSave() {
  prefs.begin("estacao", false);
  prefs.putString("ssid", cfg.ssid);      // setString grava '\0' final
  prefs.putString("pass", cfg.pass);
  prefs.putFloat("lat", cfg.lat);
  prefs.putFloat("lon", cfg.lon);
  prefs.putString("city", cfg.city);
  prefs.putString("tz", cfg.tz);
  prefs.end();
}

// ============================ Estado / sensores ==============================
enum SensorSt : uint8_t { ST_WAIT = 0, ST_OK, ST_FAIL };
struct State {
  SensorSt bmp = ST_WAIT, qmi = ST_WAIT;
  float bmpTemp = 0, bmpPress = 0;        // °C, hPa
  float gyro[3] = {0, 0, 0};              // °/s
  float acc[3] = {0, 0, 0};               // g
  float outdoorTemp = 0, tmin = 0, tmax = 0;
  int wcode = -1;
  bool isDay = true;
  bool wxValid = false;
  char wxDesc[40] = "";
  int rainProb = -1;       // prob. chuva 1h (%)
  int rainInH = -1;        // chuva comecando em X horas (-1 = sem previsao)
  float rainMm = 0;
  float humidity = -1;     // umidade relativa % (Open-Meteo)
  float pressMsl = 0;      // pressao nivel do mar hPa (Open-Meteo)
  float altitude = 0;      // m, barometrica (BMP581 vs MSL)
  float lat = 0, lon = 0;
  char locName[48] = "";
  char tzName[64] = "America/Sao_Paulo";
  int rot = 0;                            // 0/1/2/3
  bool apMode = false;
  uint32_t wxAgeMin = 999;
} st;
static volatile uint32_t lastWxOkMs = 0;
static volatile uint32_t locationVersion = 0;
static volatile bool requestApMode = false;

time_t lastNtpSync = 0;

// ============================ QMI8658 (IMU onboard) ==========================
bool qmiInit() {
  uint8_t id = 0;
  Wire.beginTransmission(QMI_ADDR);
  Wire.write((uint8_t)0x00); // WHO_AM_I
  if (Wire.endTransmission(false) != 0) return false;
  if (Wire.requestFrom(QMI_ADDR, 1) != 1) return false;
  id = Wire.read();
  Serial.printf("[QMI] WHO_AM_I=0x%02X\n", id);
  if (id != 0x05) return false;
  // reset
  Wire.beginTransmission(QMI_ADDR); Wire.write(0x60); Wire.write(0xB0); Wire.endTransmission();
  delay(15);
  // CTRL1=0x60: ADDR_AI (auto-incremento I2C) + SPI 4-wire
  Wire.beginTransmission(QMI_ADDR); Wire.write(0x02); Wire.write(0x60); Wire.endTransmission();
  // acc +/-8g 1008Hz, gyro 1008Hz
  Wire.beginTransmission(QMI_ADDR); Wire.write(0x32); Wire.write(0x24); Wire.endTransmission();
  Wire.beginTransmission(QMI_ADDR); Wire.write(0x33); Wire.write(0x23); Wire.endTransmission();
  // habilita acc+gyro
  Wire.beginTransmission(QMI_ADDR); Wire.write(0x08); Wire.write(0x03); Wire.endTransmission();
  delay(2);
  return true;
}

bool qmiRead() {
  // Datasheet: TEMP_L=0x33, AX=0x35, AY=0x37, AZ=0x39, GX=0x3B, GY=0x3D, GZ=0x3F
  Wire.beginTransmission(QMI_ADDR);
  Wire.write((uint8_t)0x33);
  if (Wire.endTransmission(false) != 0) return false;
  if (Wire.requestFrom(QMI_ADDR, 14) != 14) return false;
  uint8_t b[14];
  for (int i = 0; i < 14; i++) b[i] = Wire.read();
  int16_t raw;
  raw = (int16_t)((b[2] << 8) | b[3]);  st.acc[0] = raw / 4096.0f; // ±8g
  raw = (int16_t)((b[4] << 8) | b[5]);  st.acc[1] = raw / 4096.0f;
  raw = (int16_t)((b[6] << 8) | b[7]);  st.acc[2] = raw / 4096.0f;
  raw = (int16_t)((b[8] << 8) | b[9]);  st.gyro[0] = raw / 128.0f; // ±250dps
  raw = (int16_t)((b[10] << 8) | b[11]); st.gyro[1] = raw / 128.0f;
  raw = (int16_t)((b[12] << 8) | b[13]); st.gyro[2] = raw / 128.0f;
  return true;
}

// ============================ BMP581 (I2C externo) ===========================
Adafruit_BMP5xx bmp;
bool bmpRead() {
  if (!bmp.performReading()) return false;
  st.bmpTemp = bmp.temperature;
  st.bmpPress = bmp.pressure; // a lib ja retorna hPa
  return true;
}

// ============================ LVGL: display ==================================
static lv_color_t *dbuf;
static uint16_t *rotatedBuf;
static lv_display_t *disp;
static uint32_t scrW, scrH, bufPx;

static uint32_t millis_cb() { return millis(); }

static void disp_flush(lv_display_t *d, const lv_area_t *area, uint8_t *px) {
  uint32_t w = lv_area_get_width(area), h = lv_area_get_height(area);
  // CO5300 não troca os eixos em hardware: girar os pixels em software.
  // Horizontal com USB à direita. O painel permanece nativo 280 x 456.
  lv_area_t physical = *area;
  lv_display_rotate_area(d, &physical);
  lv_draw_sw_rotate(px, rotatedBuf, w, h, w * 2, h * 2,
                    LV_DISPLAY_ROTATION_270, LV_COLOR_FORMAT_RGB565);
  gfx->draw16bitRGBBitmap(physical.x1, physical.y1, rotatedBuf, h, w);
  lv_display_flush_ready(d);
}
static void disp_rounder(lv_event_t *e) {
  lv_area_t *a = (lv_area_t *)lv_event_get_param(e);
  a->x1 = 0; a->x2 = (int32_t)scrW - 1;
  // CO5300 exige janelas pares. Depois de girar, Y lógico vira X físico.
  // Inclui a linha vizinha no desenho para não enviar colunas ímpares.
  a->y1 &= ~1;
  a->y2 |= 1;
}

// ============================ Tela somente leitura ==========================
// A tela não tem áreas clicáveis. Toda a configuração é feita pelo navegador.
static lv_obj_t *lblClock, *lblDate, *lblWxTemp, *lblWxDesc, *lblWxMini;
static lv_obj_t *lblBmpT, *lblBmpP, *lblAlt, *lblHum;
static lv_obj_t *lblNetMode, *lblNetMain, *lblNetHelp;
static lv_obj_t *imgWx;
static lv_style_t stCard;

static const char *wcodeDesc(int c) {
  switch (c) {
    case 0: return "Ceu limpo";
    case 1: case 2: return "Parc. nublado";
    case 3: return "Nublado";
    case 45: case 48: return "Nevoeiro";
    case 51: case 53: case 55: return "Garoa";
    case 61: case 63: case 65: return "Chuva";
    case 66: case 67: return "Chuva congel.";
    case 71: case 73: case 75: return "Neve";
    case 80: case 81: case 82: return "Pancadas";
    case 95: return "Tempestade";
    case 96: case 99: return "Tmd. c/ granizo";
    default: return "-";
  }
}

static const lv_image_dsc_t *wcodeIcon(int c) {
  if (c == 0 || c == 1) return &icon_sun;
  if (c == 2) return &icon_suncloud;
  if (c == 3) return &icon_cloud;
  if (c == 45 || c == 48) return &icon_fog;
  if (c >= 51 && c <= 67) return &icon_rain;
  if (c >= 71 && c <= 77) return &icon_snow;
  if (c >= 80 && c <= 82) return &icon_sunrain;
  if (c >= 95) return &icon_storm;
  return &icon_cloud;
}

static lv_obj_t *makeCard(lv_obj_t *parent, int x, int y, int width, int height) {
  lv_obj_t *card = lv_obj_create(parent);
  lv_obj_add_style(card, &stCard, 0);
  lv_obj_set_pos(card, x, y);
  lv_obj_set_size(card, width, height);
  lv_obj_clear_flag(card, LV_OBJ_FLAG_SCROLLABLE);
  return card;
}

static lv_obj_t *mkLabel(lv_obj_t *parent, const lv_font_t *font,
                         uint32_t color, int x, int y, int width) {
  lv_obj_t *label = lv_label_create(parent);
  lv_obj_set_style_text_font(label, font, 0);
  lv_obj_set_style_text_color(label, lv_color_hex(color), 0);
  lv_obj_set_pos(label, x, y);
  lv_obj_set_width(label, width);
  lv_label_set_long_mode(label, LV_LABEL_LONG_CLIP);
  lv_label_set_text(label, "--");
  return label;
}

static void uiInit() {
  lv_style_init(&stCard);
  lv_style_set_bg_color(&stCard, lv_color_hex(0x141c2b));
  lv_style_set_border_color(&stCard, lv_color_hex(0x304159));
  lv_style_set_border_width(&stCard, 1);
  lv_style_set_radius(&stCard, 12);
  lv_style_set_pad_all(&stCard, 0);

  lv_obj_t *scr = lv_screen_active();
  lv_obj_set_style_bg_color(scr, lv_color_hex(0x09111f), 0);
  lv_obj_clear_flag(scr, LV_OBJ_FLAG_SCROLLABLE);

  // Cada linha ocupa uma área fixa; nenhuma atualização reposiciona textos.
  lv_obj_t *clockCard = makeCard(scr, 8, 8, 440, 40);
  lblClock = mkLabel(clockCard, &lv_font_montserrat_28, 0xffffff, 12, 4, 150);
  lblDate = mkLabel(clockCard, &lv_font_montserrat_12, 0x9db2cc, 174, 13, 250);

  lv_obj_t *sensorCard = makeCard(scr, 8, 56, 264, 154);
  lv_obj_t *sensorTitle = mkLabel(sensorCard, &lv_font_montserrat_12, 0x9db2cc, 12, 10, 238);
  lv_label_set_text(sensorTitle, "TEMPERATURA DO SENSOR");
  lblBmpT = mkLabel(sensorCard, &lv_font_montserrat_48, 0x70dff4, 12, 32, 238);
  lblBmpP = mkLabel(sensorCard, &lv_font_montserrat_20, 0xc4a8ff, 12, 100, 238);
  lblAlt = mkLabel(sensorCard, &lv_font_montserrat_14, 0xa1e7a7, 12, 132, 238);

  lv_obj_t *weatherCard = makeCard(scr, 280, 56, 168, 154);
  imgWx = lv_image_create(weatherCard);
  lv_image_set_src(imgWx, &icon_cloud);
  lv_obj_set_pos(imgWx, 8, 8);
  lblWxTemp = mkLabel(weatherCard, &lv_font_montserrat_14, 0xffd174, 86, 31, 72);
  lblWxDesc = mkLabel(weatherCard, &lv_font_montserrat_12, 0xe7eefb, 10, 85, 146);
  lblWxMini = mkLabel(weatherCard, &lv_font_montserrat_12, 0x9db2cc, 10, 108, 146);
  lblHum = mkLabel(weatherCard, &lv_font_montserrat_12, 0xffcf78, 10, 131, 146);

  lv_obj_t *networkCard = makeCard(scr, 8, 218, 440, 54);
  lblNetMode = mkLabel(networkCard, &lv_font_montserrat_12, 0x9db2cc, 10, 6, 418);
  lblNetMain = mkLabel(networkCard, &lv_font_montserrat_14, 0xd8e7f4, 10, 29, 230);
  lblNetHelp = mkLabel(networkCard, &lv_font_montserrat_12, 0x9db2cc, 248, 30, 180);
}

// ============================ WiFi / hora / previsão =========================
WiFiMulti wifiMulti;
WebServer server(80);
DNSServer dns;

#include "web_page.h"

static String ipStr() { return st.apMode ? WiFi.softAPIP().toString() : WiFi.localIP().toString(); }

static const char *posixTz(const char *name) {
  // newlib no ESP32 espera regras POSIX, nao identificadores IANA.
  if (!strcmp(name, "America/Sao_Paulo") || !strcmp(name, "America/Fortaleza") ||
      !strcmp(name, "America/Recife") || !strcmp(name, "America/Bahia") ||
      !strcmp(name, "America/Belem")) return "BRT3";
  if (!strcmp(name, "America/Manaus") || !strcmp(name, "America/Cuiaba") ||
      !strcmp(name, "America/Porto_Velho") || !strcmp(name, "America/Boa_Vista")) return "AMT4";
  if (!strcmp(name, "America/Rio_Branco") || !strcmp(name, "America/Eirunepe")) return "ACT5";
  if (!strcmp(name, "America/Noronha")) return "FNT2";
  if (!strcmp(name, "UTC")) return "UTC0";
  return name; // aceita regras POSIX informadas diretamente na configuracao
}
void timeInit() {
  configTzTime(posixTz(cfg.tz), "pool.ntp.org", "time.nist.gov");
}
void geoLocate() {
  HTTPClient h;
  h.setConnectTimeout(5000); h.setTimeout(5000);
  if (!h.begin("http://ip-api.com/json/?fields=status,lat,lon,timezone,city")) return;
  if (h.GET() == 200) {
    JsonDocument *dp = new JsonDocument();
    JsonDocument &d = *dp;
    bool ok = !deserializeJson(d, h.getString());
    if (ok && d["status"] == "success") {
        st.lat = d["lat"] | 0.0f;
        st.lon = d["lon"] | 0.0f;
        strlcpy(st.tzName, d["timezone"] | "UTC", sizeof(st.tzName));
        snprintf(st.locName, sizeof(st.locName), "%s", d["city"] | "Desconhecido");
        // usa geo do IP se usuário não fixou manual
        if (cfg.lat == 0 && cfg.lon == 0) {
          cfg.lat = st.lat; cfg.lon = st.lon;
          strlcpy(cfg.tz, st.tzName, sizeof(cfg.tz));
          strlcpy(cfg.city, st.locName, sizeof(cfg.city));
          cfgSave();
          timeInit();
        }
        Serial.printf("[GEO] %s %.4f,%.4f tz=%s\n", st.locName, st.lat, st.lon, st.tzName);
    }
    delete dp;
  }
  h.end();
}
void fetchWeather() {
  if (WiFi.status() != WL_CONNECTED) return;
  HTTPClient h;
  h.setConnectTimeout(3000); h.setTimeout(4000); // travar o loop o minimo possivel
  char url[512];
  snprintf(url, sizeof(url),
           "https://api.open-meteo.com/v1/forecast?latitude=%.4f&longitude=%.4f"
           "&current=temperature_2m,weather_code,is_day,precipitation,relative_humidity_2m,pressure_msl"
           "&hourly=precipitation_probability,precipitation,weather_code"
           "&daily=temperature_2m_max,temperature_2m_min,precipitation_probability_max"
           "&forecast_days=2&timezone=auto",
           cfg.lat, cfg.lon);
  if (!h.begin(url)) { Serial.println("[WX] begin falhou (url?)"); return; }
  int code = h.GET();
  if (code == 200) {
    JsonDocument *dp = new JsonDocument();
    JsonDocument &d = *dp;
    if (!deserializeJson(d, h.getString())) {
      st.outdoorTemp = d["current"]["temperature_2m"] | 0.0f;
      st.wcode = d["current"]["weather_code"] | -1;
      st.isDay = (d["current"]["is_day"] | 1) != 0;
      st.humidity = d["current"]["relative_humidity_2m"] | -1.0f;
      st.pressMsl = d["current"]["pressure_msl"] | 0.0f;
      st.tmax = d["daily"]["temperature_2m_max"][0] | 0.0f;
      st.tmin = d["daily"]["temperature_2m_min"][0] | 0.0f;
      strlcpy(st.wxDesc, wcodeDesc(st.wcode), sizeof(st.wxDesc));
      // ----- alerta de chuva: procura 1a hora com prob >= 40% nas proximas 12h
      st.rainProb = -1; st.rainInH = -1; st.rainMm = 0;
      time_t now = time(nullptr);
      struct tm tmv; localtime_r(&now, &tmv);
      int curHourUtc = tmv.tm_hour; // hora local == indice hourly (timezone=auto)
      JsonArray prob = d["hourly"]["precipitation_probability"];
      JsonArray mm = d["hourly"]["precipitation"];
      // acha indice da hora atual (hourly comeca 00:00 de hoje local)
      int startIdx = tmv.tm_hour;
      for (int i = startIdx; i < (int)prob.size() && i < startIdx + 12; i++) {
        int p = prob[i] | -1;
        if (p >= 40) {
          st.rainInH = i - startIdx;
          st.rainProb = p;
          st.rainMm = mm[i] | 0.0f;
          break;
        }
      }
      if (st.rainInH == 0) st.rainProb = st.rainProb; // agora
      st.wxValid = true;
      st.wxAgeMin = 0;
      lastWxOkMs = millis();
      Serial.printf("[WX] %.1fC %s | chuva: prob=%d%% em %dh (%.1fmm)\n",
                    st.outdoorTemp, st.wxDesc, st.rainProb, st.rainInH, st.rainMm);
    }
    delete dp;
  } else {
    Serial.printf("[WX] HTTP %d\n", code);
  }
  h.end();
}

// HTTP pode esperar varios segundos; manter estas consultas fora do loop do LVGL.
static void weatherTask(void *) {
  timeInit();
  uint32_t lastAttempt = 0;
  uint32_t lastReconnect = 0;
  uint32_t offlineSince = 0;
  uint32_t seenLocationVersion = locationVersion;
  for (;;) {
    uint32_t now = millis();
    if (seenLocationVersion != locationVersion) {
      seenLocationVersion = locationVersion;
      timeInit();
      lastAttempt = 0;
    }
    if (WiFi.status() != WL_CONNECTED) {
      if (offlineSince == 0) offlineSince = now;
      if (lastReconnect == 0 || now - lastReconnect >= 10000) {
        lastReconnect = now;
        wifiMulti.run();
      }
      if (WiFi.status() != WL_CONNECTED && millis() - offlineSince >= 60000UL) {
        Serial.println("[WiFi] sem conexao por 60 s; abrindo AP");
        requestApMode = true;
        vTaskDelete(nullptr);
      }
    } else offlineSince = 0;
    if (WiFi.status() == WL_CONNECTED &&
        (lastAttempt == 0 || now - lastAttempt >= 30UL * 60 * 1000)) {
      lastAttempt = now;
      if (cfg.lat == 0 && cfg.lon == 0) geoLocate();
      if (cfg.lat != 0 || cfg.lon != 0) fetchWeather();
    }
    vTaskDelay(pdMS_TO_TICKS(1000));
  }
}

void handleRoot() { server.send_P(200, "text/html", PAGE); }
void handleStatus() {
  JsonDocument d;
  char clk[40];
  time_t now = time(nullptr);
  struct tm tmv;
  localtime_r(&now, &tmv);
  strftime(clk, sizeof(clk), "%d/%m %H:%M:%S", &tmv);
  d["clock"] = clk;
  d["bmp_ok"] = st.bmp == ST_OK;
  d["qmi_ok"] = st.qmi == ST_OK;
  d["bmp_temp"] = st.bmpTemp;
  d["bmp_press"] = st.bmpPress;
  JsonArray g = d["gyro"].to<JsonArray>();
  g.add(round(st.gyro[0] * 10) / 10.0); g.add(round(st.gyro[1] * 10) / 10.0); g.add(round(st.gyro[2] * 10) / 10.0);
  d["outdoor_temp"] = st.outdoorTemp;
  d["tmin"] = st.tmin; d["tmax"] = st.tmax;
  d["wx_desc"] = st.wxDesc;
  d["wcode"] = st.wcode;
  d["is_day"] = st.isDay;
  d["wx_age_min"] = lastWxOkMs ? (millis() - lastWxOkMs) / 60000UL : 999;
  d["rain_prob"] = st.rainProb;
  d["rain_in_h"] = st.rainInH;
  d["rain_mm"] = (int)(st.rainMm * 10) / 10.0;
  d["humidity"] = st.humidity;
  d["altitude"] = (int)(st.altitude);
  d["press_msl"] = (int)st.pressMsl;
  d["lat"] = cfg.lat; d["lon"] = cfg.lon;
  d["tz"] = cfg.tz;
  d["loc"] = strlen(cfg.city) ? cfg.city : "manual";
  d["net"] = st.apMode ? "AP" : (WiFi.status() == WL_CONNECTED ? "WiFi" : "off");
  d["ip"] = ipStr();
  d["touch_enabled"] = false;
  d["display_width"] = scrW;
  d["display_height"] = scrH;
  d["display_usb_side"] = "right";
  String o; serializeJson(d, o);
  server.send(200, "application/json", o);
}
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
void loop() {
  uint32_t ms = millis();

  if (requestApMode && !st.apMode) {
    startAP();
    if (st.apMode) {
      requestApMode = false;
      st.wxValid = false;
      st.wxDesc[0] = 0;
      st.rainInH = -1;
      server.begin();
      uiTick();
    }
  }

  if (st.apMode) dns.processNextRequest();
  server.handleClient();

  if (ms - tLastSensor >= 200) {
    tLastSensor = ms;
    if (st.qmi == ST_OK) qmiRead();
    static uint32_t tLastBmp = 0;
    if (st.bmp == ST_OK && ms - tLastBmp >= 1000) { tLastBmp = ms; bmpRead(); }

    // retry de sensores que falharam no boot (ex.: plugados depois)
    if ((st.bmp == ST_FAIL || st.qmi == ST_FAIL) && ms - tLastSensorRetry >= 5000) {
      tLastSensorRetry = ms;
      if (st.bmp == ST_FAIL && bmp.begin(BMP_ADDR, &Wire)) {
        bmp.setTemperatureOversampling(BMP5XX_OVERSAMPLING_8X);
        bmp.setPressureOversampling(BMP5XX_OVERSAMPLING_8X);
        bmp.setIIRFilterCoeff(BMP5XX_IIR_FILTER_COEFF_15);
        bmp.setPowerMode(BMP5XX_POWERMODE_NORMAL);
        st.bmp = ST_OK;
        Serial.println("[BMP] encontrado no retry!");
      }
      if (st.qmi == ST_FAIL && qmiInit()) { st.qmi = ST_OK; Serial.println("[QMI] encontrado no retry!"); }
    }

    // rotação automatica DESATIVADA no painel (CO5300 nao aceita setRotation
    // em runtime — corrompe a tela). rot fixo 0.
    st.rot = 3;
  }

  if (ms - tLastUi >= 500) { tLastUi = ms; uiTick(); }
  if (ms - tLastPtrend >= 600000UL) { tLastPtrend = ms; ptrendSample(); } // 10min

  if (sdOk && ms - tLastSd >= 60000) {
    tLastSd = ms;
    File f = SD.open("/estacao.csv", FILE_APPEND);
    if (f) {
      char line[128];
      snprintf(line, sizeof(line), "%ld,%.1f,%.1f,%.0f,%.0f,%.1f,%d,%d",
               (long)time(nullptr), st.bmpTemp, st.bmpPress, st.altitude,
               st.humidity < 0 ? -1 : st.humidity, st.outdoorTemp, st.rainProb, st.rainInH);
      f.println(line);
      f.close();
    }
  }
  if (ms - tLastLog >= 10000) { tLastLog = ms; debugLog(); }

  if (!st.apMode) {
    if (time(nullptr) < 1600000000 || difftime(time(nullptr), lastNtpSync) > 3600) {
      lastNtpSync = time(nullptr);
    }
  }

  uint32_t delay_ms = lv_timer_handler();
  delay(delay_ms < 5 ? 5 : (delay_ms > 20 ? 20 : delay_ms));
}

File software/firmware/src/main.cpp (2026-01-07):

/**
 * @file main.cpp
 * @brief Firmware principal para Tiny Water Station Mobile
 * 
 * Este firmware controla todos os sensores, comunicação LoRa, GPS,
 * display LCD e datalogger para a Tiny Water Station Mobile.
 * 
 * Hardware: ESP32-S3-WROOM-1-N16R8
 * Versão: 2.1.0
 * Framework: Arduino
 * 
 * @author CIANDRINI
 * @date 2026
 */

#include <Arduino.h>
#include <Wire.h>
#include <SPI.h>
#include <SD.h>
#include <TinyGPS++.h>
#include <Adafruit_BME680.h>
#include <RadioLib.h>

// ==================== Configurações ====================

// Debug
#define DEBUG_LEVEL 2  // 0: Off, 1: Error, 2: Info, 3: Debug
#ifdef DEBUG_LEVEL
  #define DBG_PRINT(level, fmt, ...) \
    if (DEBUG_LEVEL >= level) { \
      Serial.printf(fmt, ##__VA_ARGS__); \
    }
#else
  #define DBG_PRINT(level, fmt, ...)
#endif

// I2C - Barramento de sensores
#ifndef I2C_SDA
  #define I2C_SDA 47
#endif
#ifndef I2C_SCL
  #define I2C_SCL 48
#endif

// UART - GPS
#ifndef GPS_RX
  #define GPS_RX 17
#endif
#ifndef GPS_TX
  #define GPS_TX 18
#endif

// SPI - Compartilhado
#define SPI_MOSI 11
#define SPI_MISO 13
#define SPI_SCK 12

// Seletores de Chip (CS)
#ifndef SD_CS
  #define SD_CS 21
#endif
#ifndef LCD_CS
  #define LCD_CS 9
#endif
#ifndef LCD_DC
  #define LCD_DC 15
#endif
#ifndef LORA_CS
  #define LORA_CS 10
#endif
#ifndef LORA_DIO1
  #define LORA_DIO1 14
#endif

// ==================== Objetos Globais ====================

// Sensores
Adafruit_BME680 bme688;  // Sensor de ambiente (temp, umid, press, gas)

// Comunicação
TinyGPSPlus gps;  // Parser GPS

// LoRa
SX1262 lora = new Module(LORA_CS, LORA_DIO1, -1, -1);

// Arquivos
File logFile;

// Estrutura de dados dos sensores
struct SensorData {
  // GPS
  float latitude = 0.0;
  float longitude = 0.0;
  float altitude = 0.0;
  float velocity = 0.0;
  bool gpsFix = false;
  
  // BME688 - Ambiente
  float temperature = 0.0;
  float humidity = 0.0;
  float pressure = 0.0;
  float gasResistance = 0.0;
  
  // Sistema
  float batteryPercent = 0.0;
  uint32_t timestamp = 0;
  int16_t loraRSSI = 0;
};

SensorData sensorData;

// ==================== Funções Auxiliares ====================

/**
 * @brief Inicializa o barramento I2C
 */
void initI2C() {
  Wire.begin(I2C_SDA, I2C_SCL, 400000);  // 400kHz Fast Mode
  DBG_PRINT(2, "[I2C] Inicializado (SDA=%d, SCL=%d)\n", I2C_SDA, I2C_SCL);
}

/**
 * @brief Verifica se um sensor I2C está presente
 * @param address Endereço I2C do sensor
 * @param name Nome do sensor para debug
 * @return true se sensor detectado, false caso contrário
 */
bool checkI2CDevice(uint8_t address, const char* name) {
  Wire.beginTransmission(address);
  uint8_t error = Wire.endTransmission();
  
  if (error == 0) {
    DBG_PRINT(2, "[I2C] Sensor %s detectado em 0x%02X\n", name, address);
    return true;
  } else {
    DBG_PRINT(1, "[I2C] Sensor %s NÃO detectado em 0x%02X (erro=%d)\n", name, address, error);
    return false;
  }
}

/**
 * @brief Inicializa o sensor BME688
 */
bool initBME688() {
  if (!bme688.begin(0x77)) {  // Endereço padrão I2C
    DBG_PRINT(1, "[BME688] Falha na inicialização\n");
    return false;
  }
  
  // Configuração do BME688
  bme688.setTemperatureOversampling(BME680_OS_8X);
  bme688.setHumidityOversampling(BME680_OS_2X);
  bme688.setPressureOversampling(BME680_OS_4X);
  bme688.setIIRFilterSize(BME680_FILTER_SIZE_3);
  bme688.setGasHeater(320, 150);  // 320°C por 150ms
  
  DBG_PRINT(2, "[BME688] Inicializado com sucesso\n");
  return true;
}

/**
 * @brief Inicializa o módulo LoRa
 */
bool initLoRa() {
  // Inicializa o módulo LoRa
  int state = lora.begin(915.0);  // Frequência 915 MHz
  
  if (state == RADIOLIB_ERR_NONE) {
    DBG_PRINT(2, "[LoRa] Inicializado com sucesso (915 MHz)\n");
    
    // Configuração adicional
    lora.setBandwidth(125.0);
    lora.setSpreadingFactor(9);
    lora.setCodingRate(7);
    lora.setOutputPower(17);
    
    return true;
  } else {
    DBG_PRINT(1, "[LoRa] Falha na inicialização (erro=%d)\n", state);
    return false;
  }
}

/**
 * @brief Inicializa o cartão SD
 */
bool initSD() {
  if (!SD.begin(SD_CS, SPI, 25000000)) {  // 25MHz max clock
    DBG_PRINT(1, "[SD] Falha na inicialização\n");
    return false;
  }
  
  DBG_PRINT(2, "[SD] Inicializado com sucesso\n");
  DBG_PRINT(2, "[SD] Tipo de cartão: ");
  switch (SD.cardType()) {
    case CARD_MMC: DBG_PRINT(2, "MMC\n"); break;
    case CARD_SD:  DBG_PRINT(2, "SD\n"); break;
    case CARD_SDHC: DBG_PRINT(2, "SDHC\n"); break;
    default: DBG_PRINT(2, "UNKNOWN\n");
  }
  
  return true;
}

/**
 * @brief Inicializa o display LCD
 */
bool initDisplay() {
  DBG_PRINT(2, "[Display] Inicializando...\n");
  // TODO: Implementar inicialização do display LCD IPS 1.14"
  // Usar biblioteca TFT_eSPI ou ST7735
  DBG_PRINT(2, "[Display] Inicializado com sucesso\n");
  return true;
}

/**
 * @brief Inicializa o GPS
 */
void initGPS() {
  Serial2.begin(9600, SERIAL_8N1, GPS_RX, GPS_TX);
  DBG_PRINT(2, "[GPS] Inicializado (RX=%d, TX=%d)\n", GPS_RX, GPS_TX);
}

/**
 * @brief Lê dados do GPS
 */
void readGPS() {
  while (Serial2.available() > 0) {
    gps.encode(Serial2.read());
  }
  
  if (gps.location.isValid()) {
    sensorData.latitude = gps.location.lat();
    sensorData.longitude = gps.location.lng();
    sensorData.altitude = gps.altitude.meters();
    sensorData.velocity = gps.speed.kmph();
    sensorData.gpsFix = true;
  } else {
    sensorData.gpsFix = false;
  }
}

/**
 * @brief Lê dados do BME688
 */
void readBME688() {
  if (!bme688.performReading()) {
    DBG_PRINT(1, "[BME688] Falha na leitura\n");
    return;
  }
  
  sensorData.temperature = bme688.temperature;
  sensorData.humidity = bme688.humidity;
  sensorData.pressure = bme688.pressure / 100.0;  // hPa
  sensorData.gasResistance = bme688.gas_resistance / 1000.0;  // kOhms
}

/**
 * @brief Atualiza todos os sensores
 */
void updateSensors() {
  readGPS();
  readBME688();
  
  // TODO: Implementar leitura de outros sensores:
  // - BMP581 (pressão de alta precisão)
  // - BMA400 (acelerômetro)
  // - BMM350 (magnetômetro)
  // - LTR-390 (UV e luz)
  // - MAX17048 (bateria)
  
  sensorData.timestamp = millis();
}

/**
 * @brief Transmite dados via LoRa
 */
void transmitLoRa() {
  // Cria payload em formato JSON
  String payload = "{";
  payload += "\"lat\":" + String(sensorData.latitude, 6) + ",";
  payload += "\"lon\":" + String(sensorData.longitude, 6) + ",";
  payload += "\"alt\":" + String(sensorData.altitude, 1) + ",";
  payload += "\"temp\":" + String(sensorData.temperature, 1) + ",";
  payload += "\"hum\":" + String(sensorData.humidity, 1) + ",";
  payload += "\"pres\":" + String(sensorData.pressure, 1);
  payload += "}";
  
  int state = lora.transmit(payload.c_str());
  
  if (state == RADIOLIB_ERR_NONE) {
    DBG_PRINT(3, "[LoRa] Payload transmitido: %s\n", payload.c_str());
  } else {
    DBG_PRINT(1, "[LoRa] Falha na transmissão (erro=%d)\n", state);
  }
}
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

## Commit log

2026-01-07 New Project
    [bom_template.csv]
2026-09-24 Estacao meteorologica mini (Waveshare ESP32-S3-Touch-AMOLED-1.64 + BMP581)
    - UI LVGL 9 touch 3 abas, emojis OpenMoji
    - NTP+geoIP, Open-Meteo (chuva/min/max/umidade), BMP581 local + altitude barometrica
    - Web server de monitoramento/config, AP fallback
    - Log microSD CSV (portado do firmware de telemetria)
    - icons.py gerador de headers RGB565
2026-09-24 fix: microSD em SPI3/HSPI dedicado — SD.begin() no SPI2 conflitava com o display QSPI (tela corrompia em bloco salmao)
    - SPIClass sdSPI(HSPI) + SD.begin(38, sdSPI, 4MHz)
    - display CO5300 permanece sozinho no SPI2_HOST
2026-09-24 fix display+touch: rotacao 180 no LVGL (painel fica no rot nativo 0) + coords de touch crus
    - lv_display_set_rotation(LV_DISPLAY_ROTATION_180): LVGL 9 roda o render E o indev
    - invert coords manualmente = dupla inversao = toque espelhado (removido)
    - rot=2 no construtor CO5300 usava offsets de paisagem => UI deslocada/corrompida
    - nav bar 60px, botoes maiores, debug serial [TOUCH]/[FT]
2026-09-25 sensores primarios + tendencia barometrica + crash fix + config via web
    - BMP temp/pressao/altitude com fontes grandes no topo da tela (proposito principal)
    - ptrend: delta de pressao 3h (amostras de 10min) -> 'pressao caindo: chuva provavel'
    - fix crash: %s com bool em debugLog (LoadProhibited, boot loop = touch 'travando')
    - aba Config sem teclado: so info + reboot; edicao so via web server
    - tabCfg agora HIDDEN no init (conteudo vazava por cima das outras abas)
    - BMP lido 1x/s (antes 5x/s) — menos I2C, UI mais fluida
    - JsonDocument de geo/wx no heap
2026-09-27 case v3: tela horizontal + USB lateral pequeno + fechamento M3; firmware: display logico 456x280 (LVGL ROTATION_270)
    [caixa_integrada_corpo-3.stl, caixa_integrada_tampa-3.stl]
2026-09-27 firmware: tela estatica sem touch/menu (touchscreen fisico defeituoso) + IP em destaque + AP fallback 10min com saida automatica; fix printf quebrado do commit anterior
2026-09-27 build: platformio.ini p/ estacao_meteo + main.cpp (ctags do .ino engolia o JS da pagina web como prototype); libs via git (registry do PIO sem os pacotes)
2026-09-27 fix tela rosa: disp_rounder forçava largura lógica 456 em flush físico 280 com ROTATION_270 (áreas chegam em coords físicas) — removido; buffer 30→40 linhas
    [main.cpp]
2026-09-27 revert display: disp_rounder OBRIGATORIO no CO5300 (flush linha inteira); blit parcial rotacionado = tela rosa. Estado comprovado da foto 18:32
    [main.cpp]
2026-09-28 firmware: restaura versao GPT/Codex (UI completa + touch + retrato 180 + web_page.h) — restaurada do snapshot compilado work/build/sketch, rodando no chip; build renomeado p/ main.cpp (bug ctags do .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
    [main.cpp]
2026-09-28 feat(meteo): prioriza BMP581 em tela horizontal e painel web
    Desativa touch e menus, reduz o IP a uma faixa inferior, alinha as atualizacoes do CO5300 e abre AP automaticamente quando o Wi-Fi falha. Mantem busca de cidade e configuracao pela web. Preserva main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
